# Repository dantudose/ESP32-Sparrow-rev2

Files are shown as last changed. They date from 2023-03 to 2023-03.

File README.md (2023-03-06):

# ESP32-Sparrow-rev2

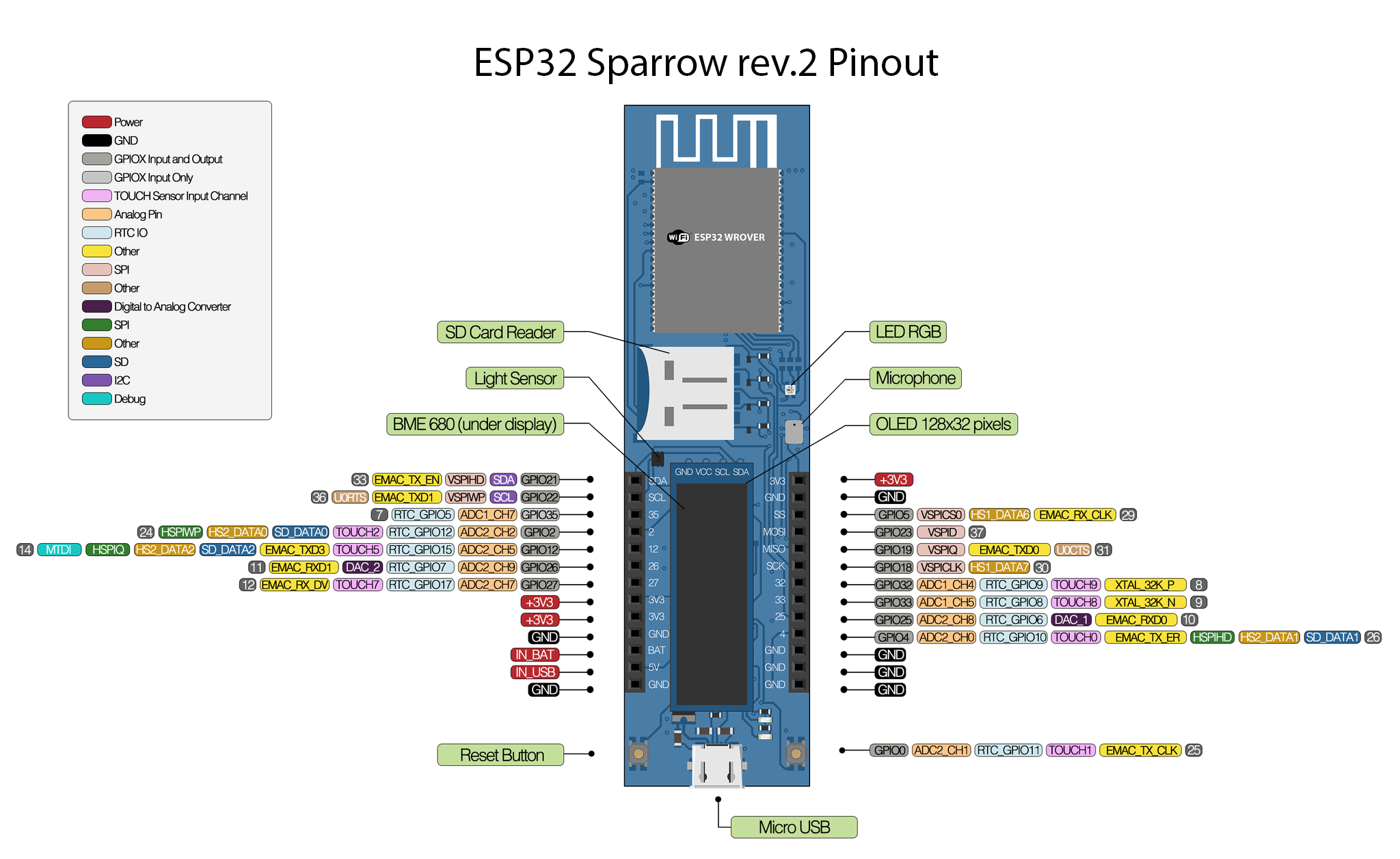
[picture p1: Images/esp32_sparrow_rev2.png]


The ESP32 Sparrow is a development board supporting the ESP32-WROVER module. It is fully Arduino-compatible and it comes with the following features:
* BME680 temperature, humidity, pressure and air quality sensor
* LTR308 ambient light sensor/luxmeter
* 128x32 SSD1306 OLED
* RGB LED
* I2S Microphone
* Micro-SD Card Holder
* 18650 LiPo battery holder with charging circuit
* Expansion headers
* USB charging/programming and data interface

<div id="cover">
  
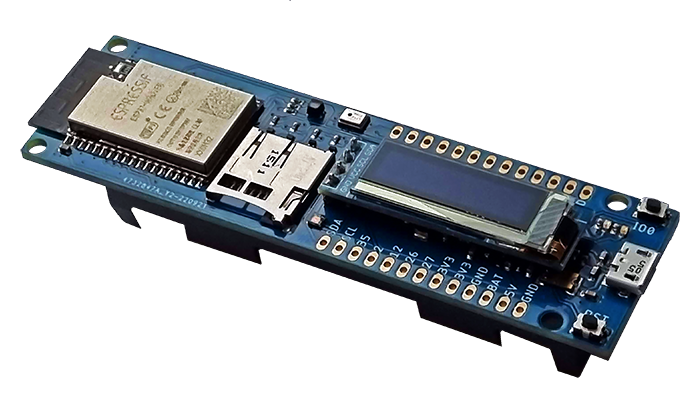
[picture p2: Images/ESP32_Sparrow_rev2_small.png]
   
</div>

Repository Contents
-------------------

* **/Hardware** - Eagle design files (.brd, .sch)
* **/Images** - Pinout and board images

Documentation
--------------
* **[Hookup Guide](https://ocw.cs.pub.ro/courses/iothings/laboratoare/2022/lab1)** - Basic hookup tutorial for ESP32 Sparrow

License Information
-------------------

This product is _**open source**_! 

Please review the LICENSE file for license information. 

Distributed as-is; no warranty is given.

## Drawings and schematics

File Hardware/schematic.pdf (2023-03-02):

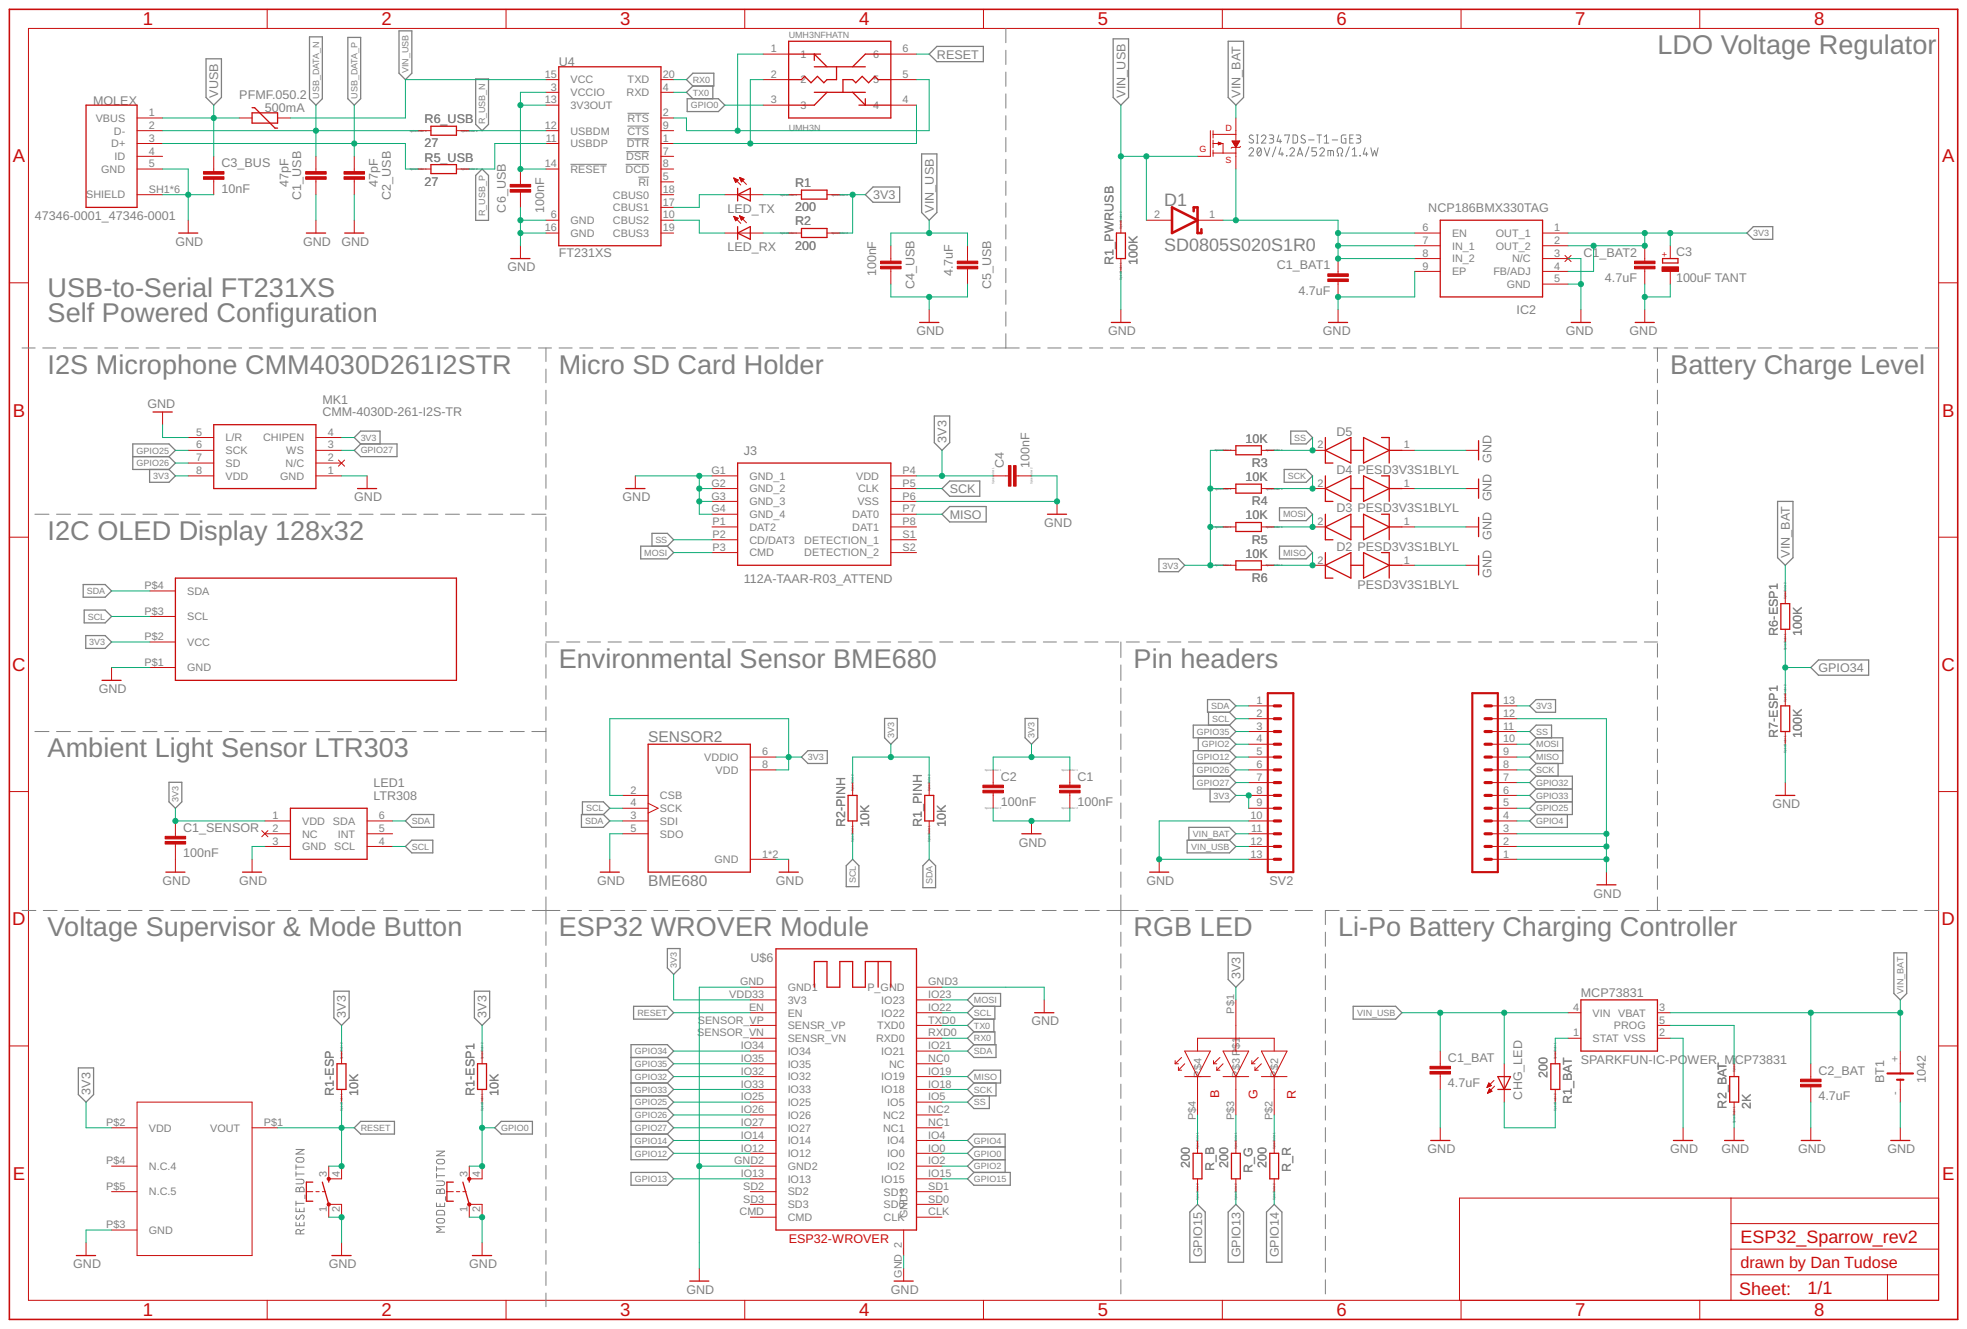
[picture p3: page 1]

UMH3NFHATN

SpiceOrder 1 SpiceOrder 2

SpiceOrder 1 SpiceOrder 2 SpiceOrder 1 SpiceOrder 2

Voltage Supervisor & Mode Button

Li-Po Battery Charging Controller

C1_BAT R1-ESP

GPIO34 | IO34 | IO21 SDA

SPARKFUN-IC-POWER_MCP73831

GPIO35 | IO32 | IO19

GPIO33 | IO33 | IO18 SCK

GPIO12 | IO12 | IO0

drawn by Dan Tudose

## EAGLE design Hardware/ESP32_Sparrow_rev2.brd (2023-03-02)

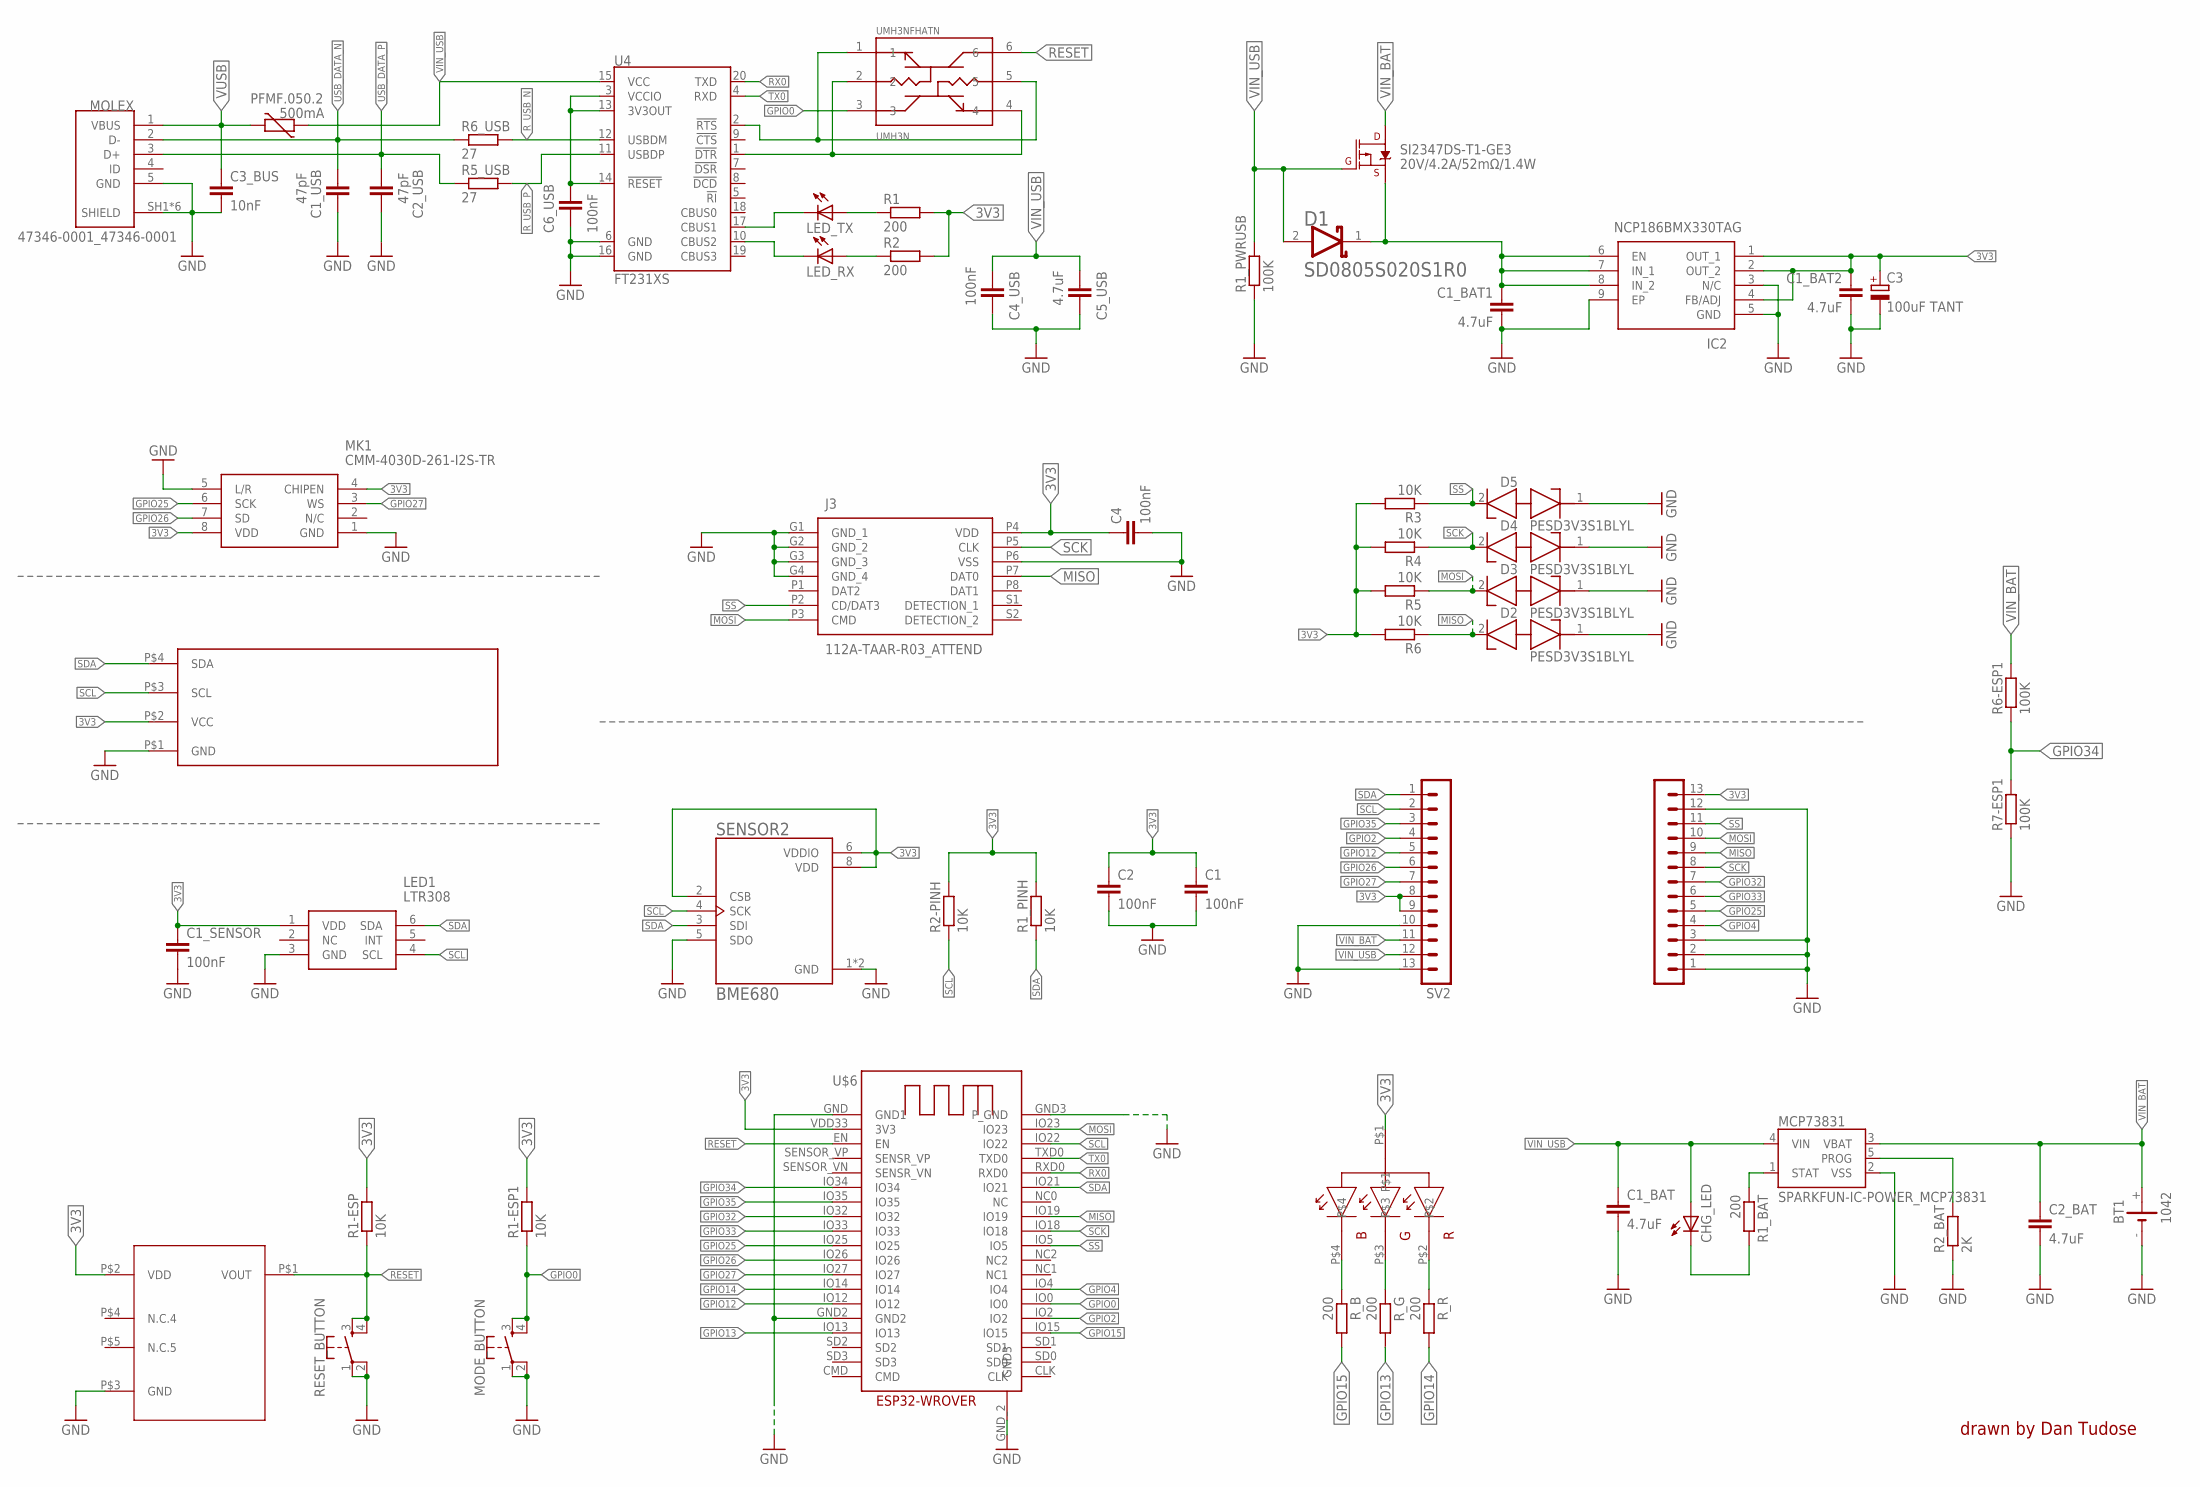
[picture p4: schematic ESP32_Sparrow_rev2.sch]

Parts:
BD48E27G-TR: BD48E27G-TR_BD48E27G-TR; BD48E27G-TR_SSOP5
BT1: 1042; BAT_1042
C1, C2, C4: 100nF; EAGLE-LTSPICE_C0402
C1_BAT, C1_BAT1, C1_BAT2, C2_BAT, C5_USB: 4.7uF; RCL_C0603
C1_SENSOR, C4_USB, C6_USB: 100nF; RCL_C0603
C1_USB, C2_USB: 47pF; RCL_C0603
C3: 100uF TANT; CT3528
C3_BUS: 10nF; RCL_C0603
CHG_LED: ADAFRUIT_LEDCHIP-LED0603; ADAFRUIT_CHIP-LED0603
D1: AVX---SD0805S020S1R0_AVX_SD0805S020S1R0AVX_SD0805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; AVX---SD0805S020S1R0_AVX_SD0805S020S1R0_0
D2, D3, D4, D5: PESD3V3S1BLYL; PESD5V0S1BL315
IC2: NCP186BMX330TAG; NCP186AMX330TAG
J3: 112A-TAAR-R03_ATTEND; 112ATAARR03ATTEND
LED1: LTR308; SAMACSYS_PARTS_LTR303ALS01
LED_RX: ADAFRUIT_LEDCHIP-LED0603; ADAFRUIT_CHIP-LED0603
LED_TX: ADAFRUIT_LEDCHIP-LED0603; ADAFRUIT_CHIP-LED0603
MCP73831: SPARKFUN-IC-POWER_MCP73831; SPARKFUN-IC-POWER_SOT23-5
MK1: CMM-4030D-261-I2S-TR; CMM4030D261I2STR
MODE_BUTTON: SPARKFUN-SWITCHES_MOMENTARY-SWITCH-SPST-2-SMD-4.6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; SPARKFUN-SWITCHES_TACTILE_SWITCH_SMD_4.6X2.8MM
MOLEX: 47346-0001_47346-0001; 47346-0001_MOLEX_47346-0001
PFMF.050.2: 500mA; VARISTOR_CT/CN1812
R1, R1_BAT, R2: 200; EAGLE-LTSPICE_R0402
R1-ESP, R1-ESP1, R1_PINH, R2-PINH, R3, R4, R5, R6: 10K; EAGLE-LTSPICE_R0402
R1_PWRUSB, R6-ESP1, R7-ESP1: 100K; EAGLE-LTSPICE_R0402
R2_BAT: 2K; EAGLE-LTSPICE_R0402
R5_USB, R6_USB: 27; EAGLE-LTSPICE_R0402
RESET_BUTTON: SPARKFUN-SWITCHES_MOMENTARY-SWITCH-SPST-2-SMD-4.6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; SPARKFUN-SWITCHES_TACTILE_SWITCH_SMD_4.6X2.8MM
R_B: 200; EAGLE-LTSPICE_R0402
R_G: 200; EAGLE-LTSPICE_R0402
R_R: 200; EAGLE-LTSPICE_R0402
SENSOR2: BME680; BME680_PSON80P300X300X100-8N
SI2347DS-T1-GE3: 20V/4.2A/52mΩ/1.4W; SPARKFUN-DISCRETESEMI_SOT23-3
SV1, SV2: MA13-1
U4: FT231XS; SPARKFUN-IC-COMMS_SSOP20_L
U$1: OLED; SIP
U$2: 150202M153130_150202M153130-RGB; 150202M153130_150202M153130
U$6: ESP32-WROVER_ESP32-WROVER
UMH3NFHATN: UMH3N; UMH3N_SOP65P210X100-6N

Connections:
3V3: BD48E27G-TR.P$2 (VDD), C1.1, C1_BAT2.1, C1_SENSOR.1, C2.1, C3.+, C4.1, IC2.1 (OUT_1), IC2.2 (OUT_2), IC2.4 (FB/ADJ), J3.P4 (VDD), LED1.1 (VDD), MK1.4 (CHIPEN), MK1.8 (VDD), R1.2, R1-ESP.2, R1-ESP1.2, R1_PINH.2, R2.2, R2-PINH.2, R3.2, R4.2, R5.2, R6.2, SENSOR2.2 (CSB), SENSOR2.6 (VDDIO), SENSOR2.8 (VDD), SV1.13, SV2.8, SV2.9, U$1.P$2 (VCC), U$2.P$1, U$6.VDD33 (3V3)
GND: BD48E27G-TR.P$3 (GND), BT1.-, C1.2, C1_BAT.2, C1_BAT1.2, C1_BAT2.2, C1_SENSOR.2, C1_USB.2, C2.2, C2_BAT.2, C2_USB.2, C3.-, C3_BUS.2, C4.2, C4_USB.2, C5_USB.2, C6_USB.2, D2.1 (K1), D3.1 (K1), D4.1 (K1), D5.1 (K1), IC2.3 (N/C), IC2.5 (GND), IC2.9 (EP), J3.G1 (GND_1), J3.G2 (GND_2), J3.G3 (GND_3), J3.G4 (GND_4), J3.P6 (VSS), LED1.3 (GND), MCP73831.2 (VSS), MK1.1 (GND), MK1.5 (L/R), MODE_BUTTON.1, MODE_BUTTON.2, MOLEX.5 (GND), MOLEX.SH1 (SHIELD), MOLEX.SH2 (SHIELD), MOLEX.SH3 (SHIELD), MOLEX.SH4 (SHIELD), MOLEX.SH5 (SHIELD), MOLEX.SH6 (SHIELD), R1_PWRUSB.1, R2_BAT.1, R7-ESP1.1, RESET_BUTTON.1, RESET_BUTTON.2, SENSOR2.1 (GND), SENSOR2.5 (SDO), SENSOR2.7 (GND), SV1.1, SV1.2, SV1.3, SV1.12, SV2.10, SV2.13, U4.6 (GND), U4.16 (GND), U$1.P$1 (GND), U$6.GND (GND1), U$6.GND2, U$6.GND3 (P_GND), U$6.GND_2 (GND3)
GPIO0: MODE_BUTTON.3, MODE_BUTTON.4, R1-ESP1.1, U$6.IO0, UMH3NFHATN.3
GPIO2: SV2.4, U$6.IO2
GPIO4: SV1.4, U$6.IO4
GPIO12: SV2.5, U$6.IO12
GPIO13: R_G.2, U$6.IO13
GPIO14: R_R.2, U$6.IO14
GPIO15: R_B.2, U$6.IO15
GPIO25: MK1.6 (SCK), SV1.5, U$6.IO25
GPIO26: MK1.7 (SD), SV2.6, U$6.IO26
GPIO27: MK1.3 (WS), SV2.7, U$6.IO27
GPIO32: SV1.7, U$6.IO32
GPIO33: SV1.6, U$6.IO33
GPIO34: R6-ESP1.1, R7-ESP1.2, U$6.IO34
GPIO35: SV2.3, U$6.IO35
MISO: D2.2 (K2), J3.P7 (DAT0), R6.1, SV1.9, U$6.IO19
MOSI: D3.2 (K2), J3.P3 (CMD), R5.1, SV1.10, U$6.IO23
unnamed: C1_BAT1.1, D1.1 (CATHODE), IC2.6 (EN), IC2.7 (IN_1), IC2.8 (IN_2), SI2347DS-T1-GE3.2 (S)
unnamed: MCP73831.1 (STAT), R1_BAT.1
unnamed: CHG_LED.C, R1_BAT.2
unnamed: MCP73831.5 (PROG), R2_BAT.2
unnamed: R_R.1, U$2.P$2
unnamed: R_G.1, U$2.P$3
unnamed: R_B.1, U$2.P$4
unnamed: C6_USB.1, U4.3 (VCCIO), U4.13 (3V3OUT), U4.14 (!RESET)
unnamed: LED_TX.A, R1.1
unnamed: LED_RX.A, R2.1
unnamed: U4.1 (!DTR), UMH3NFHATN.2, UMH3NFHATN.4
unnamed: LED_TX.C, U4.17 (CBUS1)
unnamed: LED_RX.C, U4.10 (CBUS2)
unnamed: U4.2 (!RTS), UMH3NFHATN.1, UMH3NFHATN.5
RESET: BD48E27G-TR.P$1 (VOUT), R1-ESP.1, RESET_BUTTON.3, RESET_BUTTON.4, U$6.EN, UMH3NFHATN.6
RX0: U4.20 (TXD), U$6.RXD0
R_USB_N: R6_USB.2, U4.12 (USBDM)
R_USB_P: R5_USB.2, U4.11 (USBDP)
SCK: D4.2 (K2), J3.P5 (CLK), R4.1, SV1.8, U$6.IO18
SCL: LED1.4 (SCL), R2-PINH.1, SENSOR2.4 (SCK), SV2.2, U$1.P$3 (SCL), U$6.IO22
SDA: LED1.6 (SDA), R1_PINH.1, SENSOR2.3 (SDI), SV2.1, U$1.P$4 (SDA), U$6.IO21
SS: D5.2 (K2), J3.P2 (CD/DAT3), R3.1, SV1.11, U$6.IO5
TX0: U4.4 (RXD), U$6.TXD0
USB_DATA_N: C1_USB.1, MOLEX.2 (D-), R6_USB.1
USB_DATA_P: C2_USB.1, MOLEX.3 (D+), R5_USB.1
VIN_BAT: BT1.+, C2_BAT.1, MCP73831.3 (VBAT), R6-ESP1.2, SI2347DS-T1-GE3.3 (D), SV2.11
VIN_USB: C1_BAT.1, C4_USB.1, C5_USB.1, CHG_LED.A, D1.2 (ANODE), MCP73831.4 (VIN), PFMF.050.2.1, R1_PWRUSB.2, SI2347DS-T1-GE3.1 (G), SV2.12, U4.15 (VCC)
VUSB: C3_BUS.1, MOLEX.1 (VBUS), PFMF.050.2.2

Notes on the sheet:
drawn by Dan Tudose

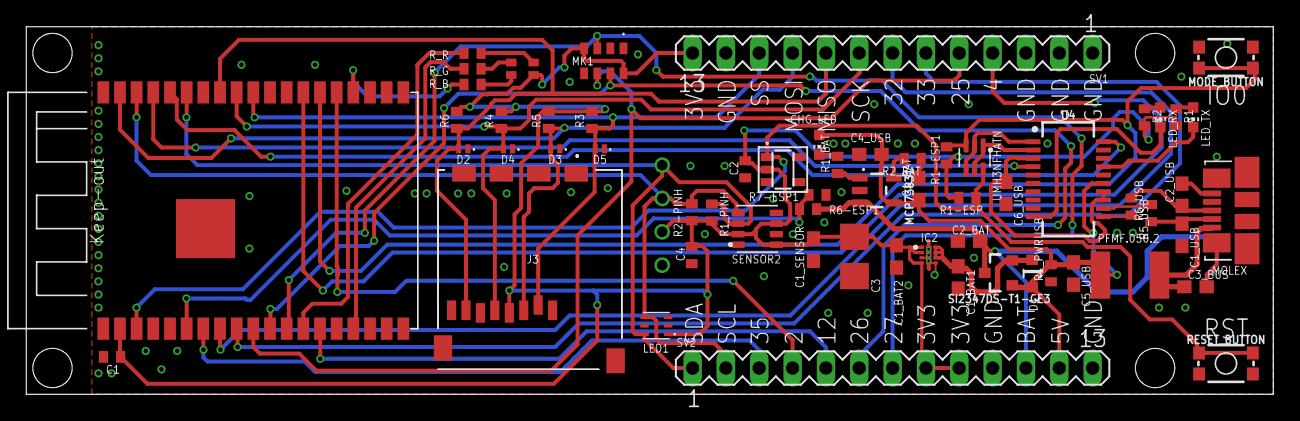
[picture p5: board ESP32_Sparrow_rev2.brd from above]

Board: 2 copper layers, 95.0 x 28.0 mm, 63 parts (1 on the bottom side), 46 nets.
